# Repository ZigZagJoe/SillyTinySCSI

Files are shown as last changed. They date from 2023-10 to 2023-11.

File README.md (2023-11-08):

SillyTinySCSI - Smallest SCSI emulator out there!
Derived from and firmware compatible with ZuluSCSI Pico OSHW.

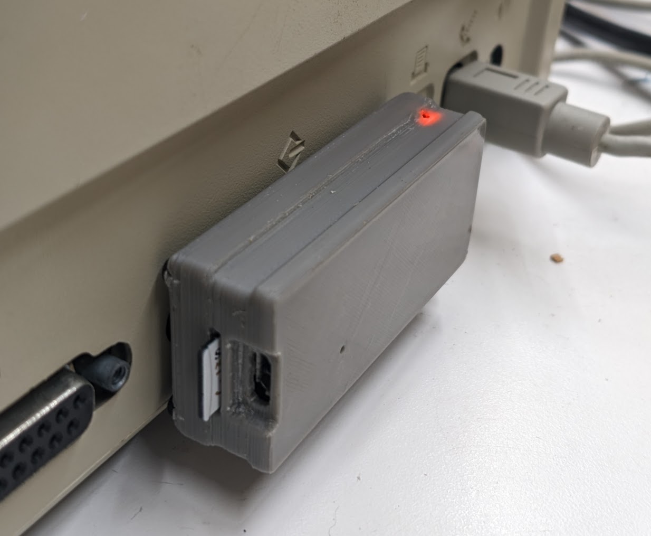
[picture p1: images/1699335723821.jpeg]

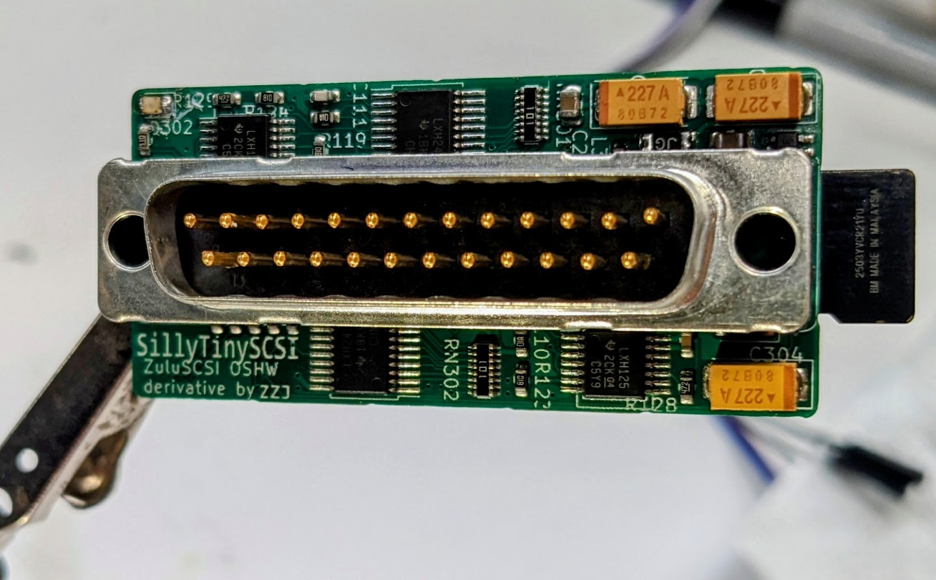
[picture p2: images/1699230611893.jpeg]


V1.0: No bugs, however it is a double-sided board.
V2.0: Design for manufacturability improvements

Case design has been validated in 0.25mm ABS on a monoprice mini. May require changes on other printers. Not yet tested.
Requires 4x M2 x 7mm (or greater) machine screws or suitable self tapping screws.
Supports everywhere is *required* when printing. Suggest line support in cura, ensure that the lines run along the length of the slots 

See here for more discussion and assembly note: https://68kmla.org/bb/index.php?threads/sillytinyscsi-smallest-scsi-emulator-zuluscsi-oshw.45830/

---------------------------
Orginal document.....
---------------------------

ZuluSCSI™ Pico Community Edition - Open Source Hardware
========================

This repository contains the KiCAD 7 schematic and PCB design files for the Pico-based ZuluSCSI™ SCSI to SD storage emulator, which is derived from the ZuluSCSI RP2040 board design. Firmware for ZuluSCSI is available at http://github.com/ZuluSCSI/ZuluSCSI-firmware.

This hardware design is licensed under the terms of the strongly reciprocal CERN OHL-S V2 license, which can be viewed in full at https://ohwr.org/cern_ohl_s_v2.txt and https://ohwr.org/cern_ohl_s_v2.pdf. 

ZuluSCSI™ is a registered trademark of Rabbit Hole Computing, and may not be used commercially without the express written consent of Rabbit Hole Computing. Individuals producing ZuluSCSI boards for personal use are hereby granted permission to use the ZuluSCSI trademark in a noncommercial capacity.

_Any_ use of the ZuluSCSI trademark in a **commercial** context requires prior written consent from Rabbit Hole Computing.

ZuluSCSI Pico OSHW board Render (top)

Firmware for ZuluSCSI is licensed under the GNU GPL Version 3, and can be found at https://github.com/zuluscsi/ZuluSCSI-firmware

Generating fabrication files
----------------------------

The component part numbers are stored in KiCAD schematic.
Manufacturing files, including assembly BOM, can be generated using [KiKit](https://github.com/yaqwsx/KiKit).

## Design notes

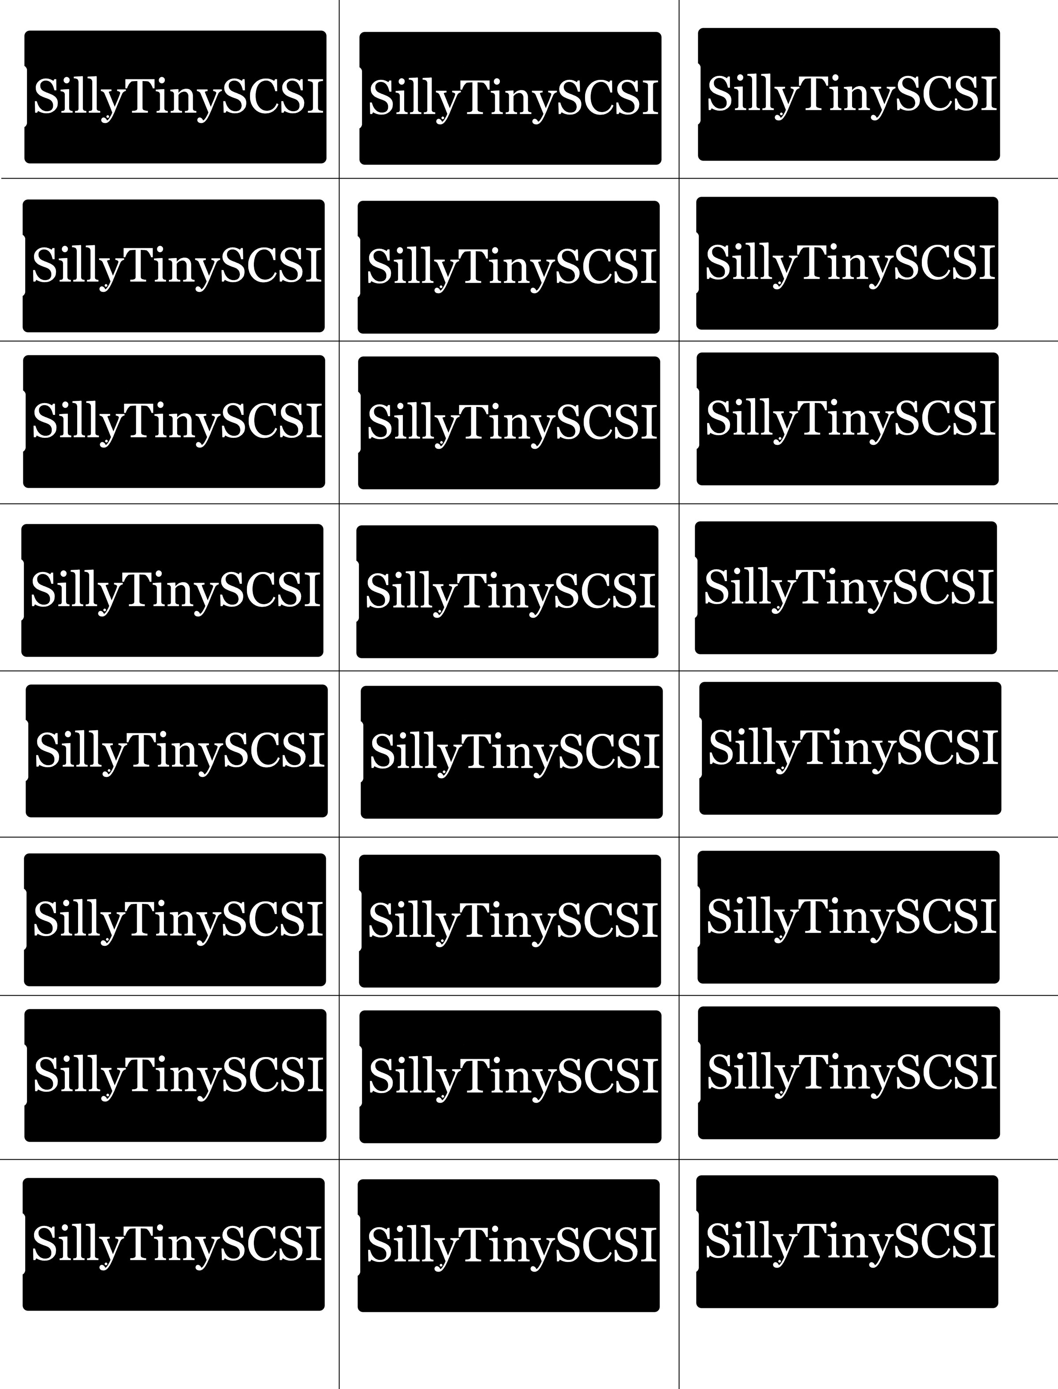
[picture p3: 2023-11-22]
label_sheet.png

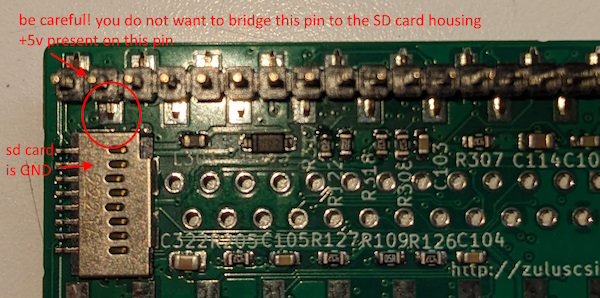
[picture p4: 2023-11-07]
images/becareful.jpg

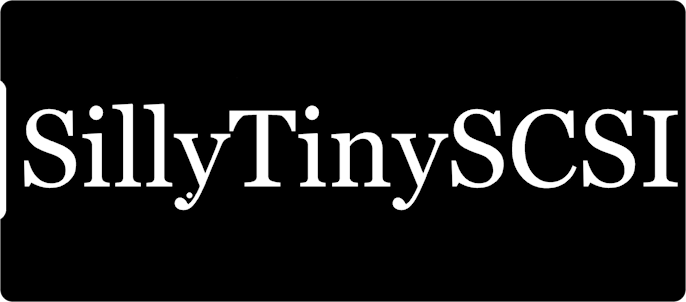
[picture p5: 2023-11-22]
label_black_300dpi.png

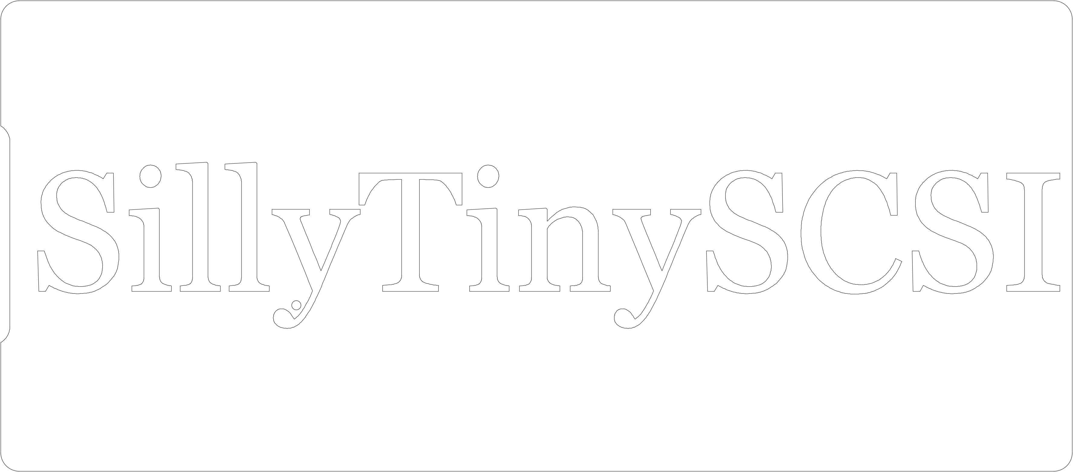
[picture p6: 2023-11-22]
label_outline.png

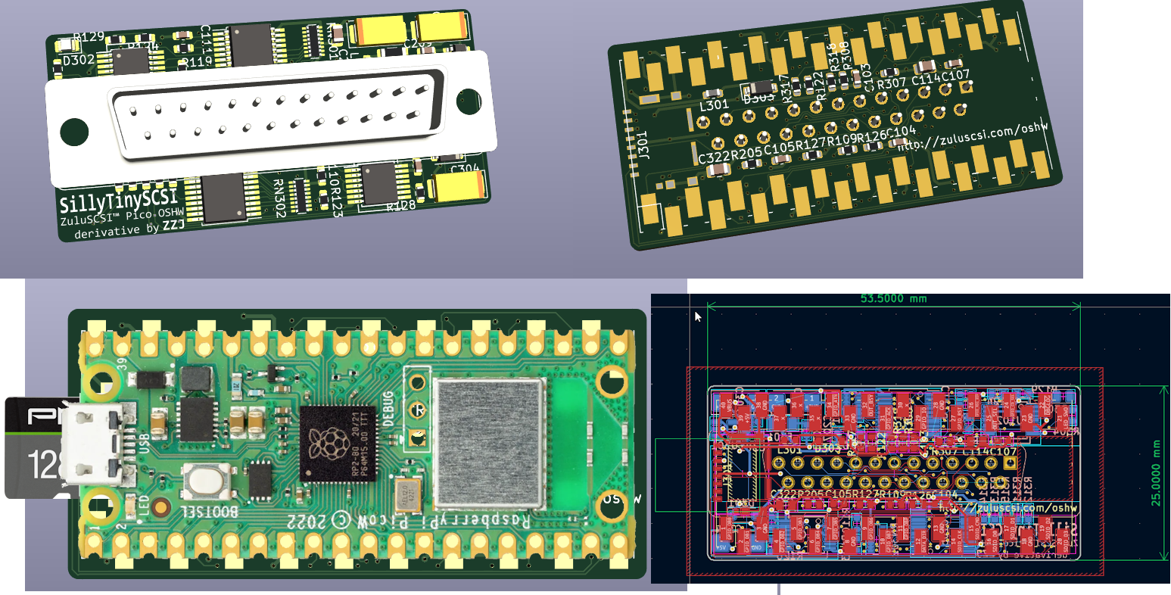
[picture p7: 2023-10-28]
images/mockup.png

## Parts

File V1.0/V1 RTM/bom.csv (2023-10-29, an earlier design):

Designator | Footprint | Quantity | Value | LCSC Part #
C103, C104, C105, C107, C312 | 0603 | 5 | 100nF | C14663
C111 | 0603 | 1 | 12pF | C38523
C114, C207, C301, C305, C322 | 0805 | 5 | 10uF | C15850
C302, C303, C304 | CP_EIA-6032-15_Kemet-U_Pad2.25x2.35mm_HandSolder | 3 | 220uF | C8023
D201, D301, D303 | D_SOD-123 | 3 | D_Schottky | C8598
D302, D304 | 0805 | 2 | LED | n/a
F301 | 1206 | 1 | 500mA Hold | C369160
J301 | microsd_molex_1051620001 | 1 | Micro_SD_Card_Det1 | n/a
J302 | DSUB-25_Male_Vertical_Small Courtyard | 1 | DB25_Plug | D25P24B4PA00LF
L301, L302 | 0603 | 2 | Ferrite_Bead_Small | C1002
R109, R110, R119 | 0603 | 3 | 110 | C22781
R122, R123, R124, R125, R317 | 0603 | 5 | 1k | C21190
R126, R127, R128, R129, R205, R307, R308, R311, R312, R313, R314, R315, R318 | 0603 | 13 | 4k7 | C23162
R304 | 0603 | 1 | 51 | C23197
RN301, RN302 | R_Array_Convex_8x0602 | 2 | 120 | C1731305
U1 | RPi_Pico_W_SMD headers | 1 | Pico W | N/A
U101, U102 | SSOP_TSSOP-14_4.4x5mm_Pitch0.65mm_PCBWay-MaskClearance0.22mm | 2 | 74LVT125 | C7042
U105, U106 | SSOP_TSSOP-20_5.3x7.2mm_P0.65mm | 2 | 74LVT245 | C7057
U301 | SOT-23-5 | 1 | TLV75728PDBVR | C2863639

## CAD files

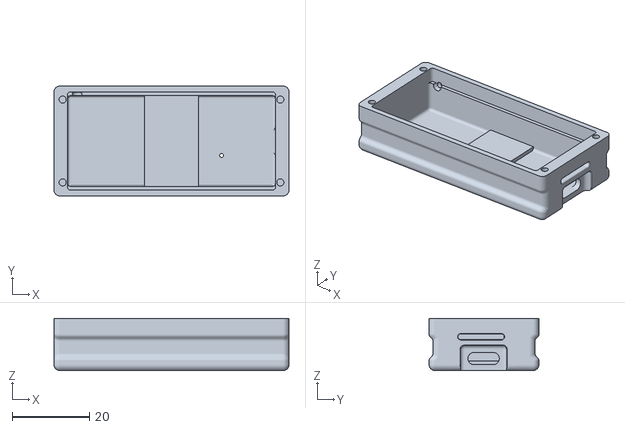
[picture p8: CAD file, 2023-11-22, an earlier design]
V1.0/case/SillyTinyScsiR1_Top v8.stl
61.0 x 28.5 x 13.5

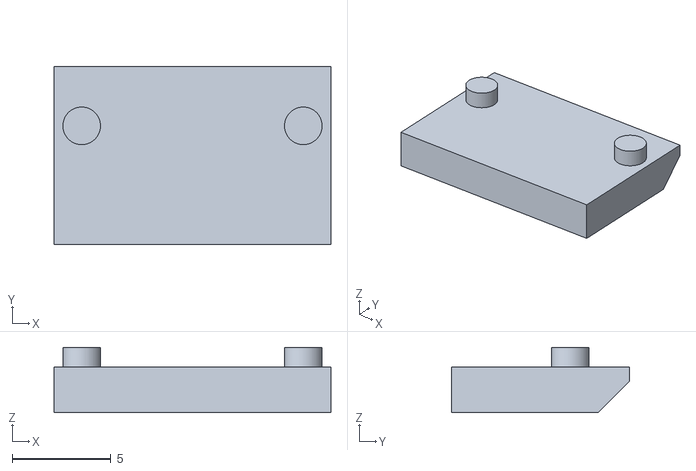
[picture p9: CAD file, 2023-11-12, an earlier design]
V1.0/case/SillyTinySCSIR1_SD_Helper v5.stl
14.0 x 9.00 x 3.30

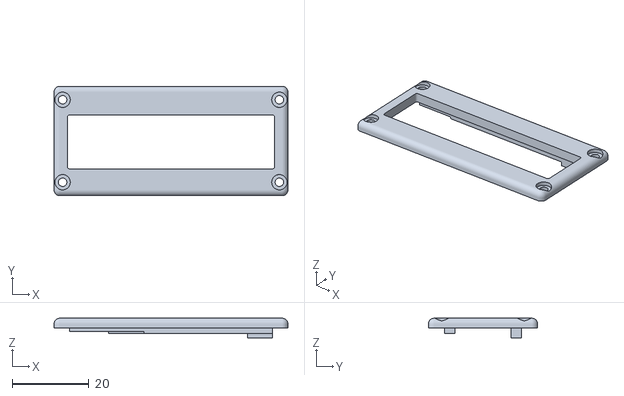
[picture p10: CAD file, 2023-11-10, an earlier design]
V1.0/case/SillyTinyScsiR1_Bottom v13.stl
61.0 x 28.5 x 5.10

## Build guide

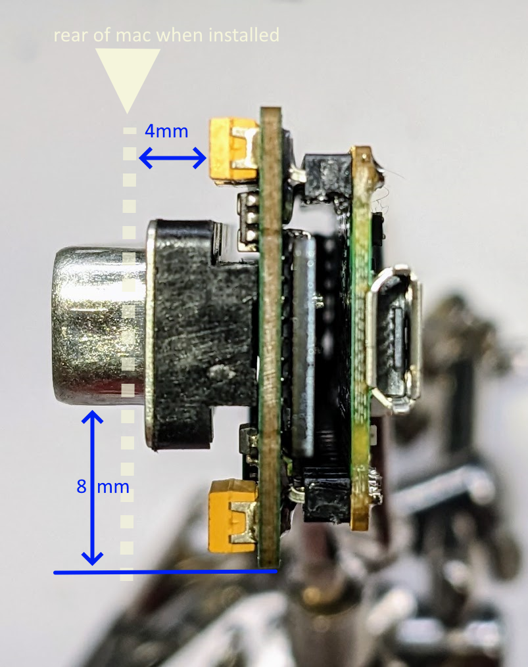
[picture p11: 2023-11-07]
images/install dims.png

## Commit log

2023-10-28 update mockup
    [SillyTinySCSI.kicad_pcb]
2023-10-29 fix BOM and proposed RTM files
    [SillyTinySCSI.kicad_pcb, SillyTinySCSI.kicad_sch, cpu.kicad_sch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]
2023-10-29 routing improvements
    [SillyTinySCSI.kicad_pcb]
2023-10-29 update regulator for manufacturing
    [SillyTinySCSI.kicad_pcb, power.kicad_sch]
2023-10-29 change to 1.2mm thickness
    [SillyTinySCSI.kicad_pcb]
2023-10-29 add prod files and update readme
    [SillyTinySCSI.kicad_pcb, bom.csv, designators.csv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]
2023-11-07 reorg, v2, dfm
    [SillyTinySCSI.csv, SillyTinySCSI.kicad_pcb, SillyTinySCSI.kicad_sch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]
2023-11-08 fix second round of DRC, new prod
    [SillyTinySCSI.kicad_pcb, SillyTinyScsiR1_Top v4.stl, bom.csv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]
2023-11-10 optimizations to buffers
    [SillyTinySCSI.kicad_pcb, SillyTinySCSI.kicad_sch, SillyTinyScsiR1_Bottom v12.stl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]
2023-11-10 reverted some nuffer changes
    [SillyTinySCSI.kicad_pcb, SillyTinySCSI.kicad_sch, bom.csv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]
2023-11-12 add case
    [SillyTinySCSIR1_SD_Helper v5.stl, SillyTinyScsiR1_Bottom v12.stl, SillyTinyScsiR1_Top v6.stl]
2023-11-13 last resistor pack
    [SillyTinySCSI.kicad_pcb, SillyTinySCSI.kicad_sch, SillyTinyScsiR1_Bottom v12.stl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]
2023-11-13 before ar
    [SillyTinySCSI.kicad_pcb, SillyTinySCSI.kicad_sch, SillyTinyScsiR1_Bottom v13.stl]
2023-11-13 before ar2
    [SillyTinySCSI.kicad_pcb]
2023-11-13 ar2, re-route
    [SillyTinySCSI.kicad_pcb]
2023-11-13 ar3 all but pwr
    [SillyTinySCSI.kicad_pcb]
2023-11-13 pwr routed
    [SillyTinySCSI.kicad_pcb, SillyTinySCSI.kicad_sch, cpu.kicad_sch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]
2023-11-13 routing and drc 1
    [SillyTinySCSI.kicad_pcb]
2023-11-15 sync up
    [SillyTinySCSI.kicad_pcb, SillyTinySCSI.kicad_sch, bom.csv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]
2023-11-22 bring current
    [SillyTinySCSI.kicad_pcb, SillyTinySCSI.kicad_sch, SillyTinyScsiR1_Top v6.stl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]
